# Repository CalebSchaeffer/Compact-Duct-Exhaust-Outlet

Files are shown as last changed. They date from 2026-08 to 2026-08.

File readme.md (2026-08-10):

# Compact Duct Exhaust Outlet
My final project for ENGR 1304 (Graphics). It was a 3d printable 4-inch exhaust outlet that took a circular input and transitioned it into a rectangular exhaust. Flaps were also in place to prevent stuff from getting in while the fan is off. 

This project was completed earlier in my CAD experience. My skills have improved since then, but expect some of the CAD to be a bit rough. 

# Assembly

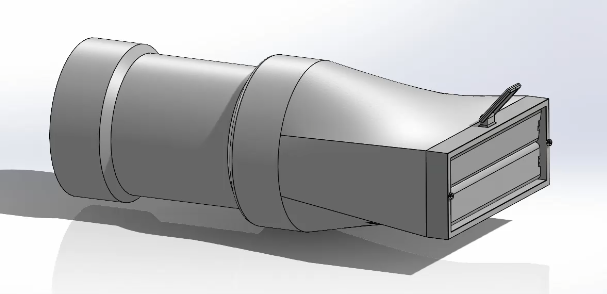
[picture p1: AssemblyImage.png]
AssemblyImage


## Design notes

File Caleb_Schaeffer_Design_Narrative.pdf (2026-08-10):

Schaeffer 1

Caleb Schaeffer
Mr. McLane
ENGR 1304
5 May 2026
Compact Duct Exhaust Outlet For this project, I designed an adapter that takes a 4-inch fan, and vents it out via a rectangular output with flaps to keep debris from going back through when air is not flowing. The assembly begins with the fan duct casing, just so that the end user can see what the adapter connects to, and that connects to the adapter. The adapter is made up of two primary parts. It has the transition piece, which takes the circular duct input and converts it to a rectangular output, and it has a piece that mounts to that which holds the flaps and mounting geometries. However, there are many more parts that went into this design/assembly.
The joints used are found at the hinges for the flaps, and on top of the flap casing, where a latch is found. To connect the flaps to the flap casing, they are press fit. To achieve this, the flap casing is made up of TPU (Thermoplastic Polyurethane), which has more flexible properties compared to other plastics, such as ABS (Acrylonitrile Butadiene Styrene), used for the other pieces. Because of the way that the joining mechanism works, the flaps are easily able to slide in given the flexibility of TPU, however, due to the shape of the joinery, they are unable to come out during typical use. Another example of this press-fit joinery is found on the top latch. The top latch connects at the top and serves as a way to mount the device to any fixtures necessary. Once again, because the casing is flexible, the latch is able to press fit on, and stay on during normal usage. Alternative ideas to this mounting were considered, such as mounting bearings and making the whole assembly two pieces that could be screwed together, however, the press-fit joinery was decided upon due to its simplicity and functionality. Every single hinge found on this design is a 1 DOF (Degree of Freedom) joint, which keeps things simple and secure.
There were many design considerations that were taken into account for this project to come to life. One of them was the understanding that additive manufacturing was to be used for the final manufacturing of the device. As such, the materials are made in additive manufacturing friendly materials, such as ABS and TPU. The only pieces that are metal are standardized screws, such as the M2 screws. As such, the entire assembly is based on the metric system due to my personal familiarity with it as well as the dominance of metric in the additive manufacturing space. The design had 3D printing as its preferred method of additive manufacturing at heart, and as such many more design considerations were taken for that. The majority of the design is able to be printed without supports, and the walls are all multiples of 0.4mm, with most of them being 4mm thick. This is important, as 0.4mm is the standardized nozzle size for most 3D printers, and most walls are able to be set to 4mm thick, meaning that you get clean surfaces and extrusion from a 3D printer. Another consideration that was made specifically in the spirit of 3D printing was the chamfers. Due to a 3D printing phenomenon called “elephant’s foot” parts may come out with the bottom surfaces that are attached to the bed looking bulged. Adding a chamfer of ~0.2mm helps with this, as if such a phenomenon happens, then it is quickly hidden away, and keeps the corner looking perfectly square. The design is also able to be modified as to the end user’s goals. If the end user is using a different duct fan, then they are able to edit the dimensions of the adapter to meet their parameters. Clearance was also important to the project due to the dimensional accuracy of the 3D printer used, however, in SolidWorks, these are not added in most sections. This is because most 3D printer users are familiar with their printers, know the shrinkage per material, and know the overall dimensional accuracy of their 3D printer. Due to this, the end user is able to go back into the SolidWorks file and edit the file to their specification. All of these considerations came together to make a design that works elegantly, is able to be manufactured easily, and can be easily scaled.
A few technical difficulties were found along the way for this design. One technical difficulty I faced was the usage of SolidWorks. Due to not being as familiar with SolidWorks as I am with other CAD programs, I found that there were particular functions or sketching tools that I needed that I was unable to find quickly. Eventually, I was able to find everything that was needed, however, this led to a significant time bump. Another technical difficulty was with poor planning as to the design of the project. At the start of the project, I did not have the dimensions for everything, and I was not certain what the end result would fully look like. To minimize any issues and further complicating things, I made the majority of the project in another CAD program that I am more familiar with to make sure everything worked up to spec, and then moved it over to SolidWorks. However, the majority of the designing was still done in SolidWorks, until I wasn’t certain how I wanted a certain piece to turn out as.

Standard M2 screws were not designed by me. They were created by Ioan Skurka and posted on GrabCAD.
Material Properties:

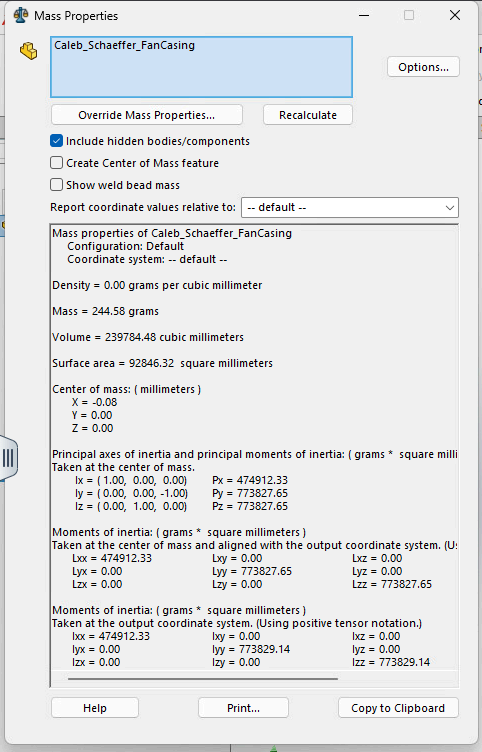
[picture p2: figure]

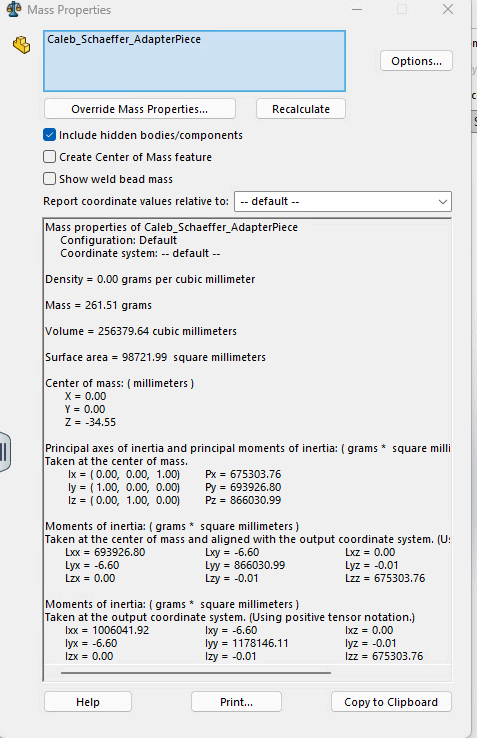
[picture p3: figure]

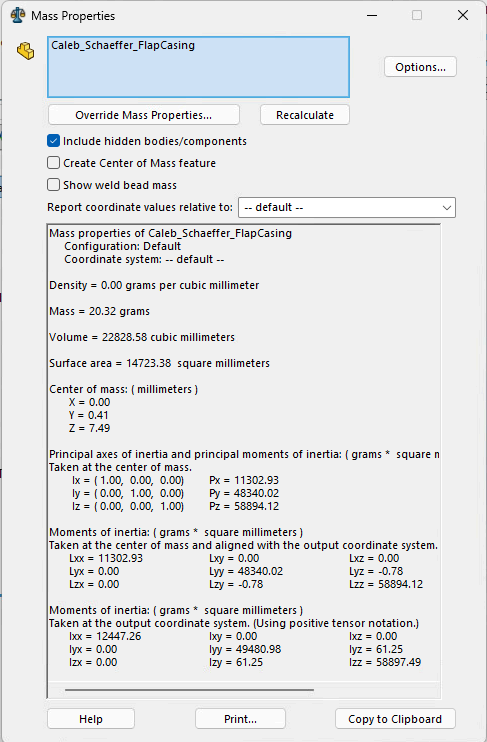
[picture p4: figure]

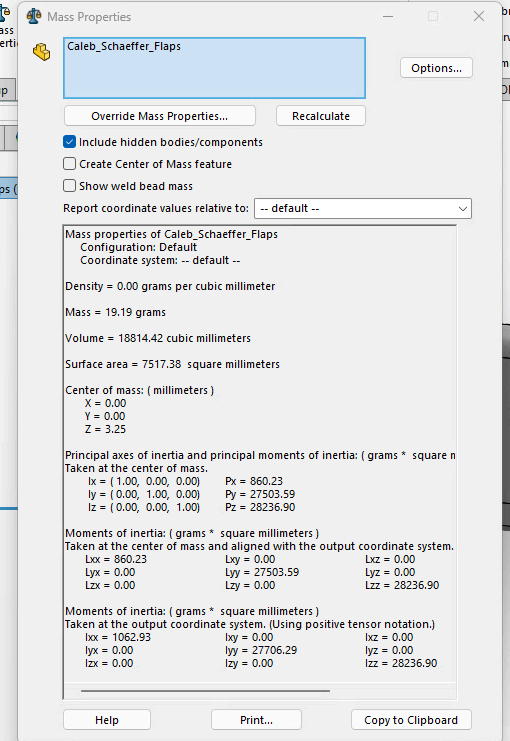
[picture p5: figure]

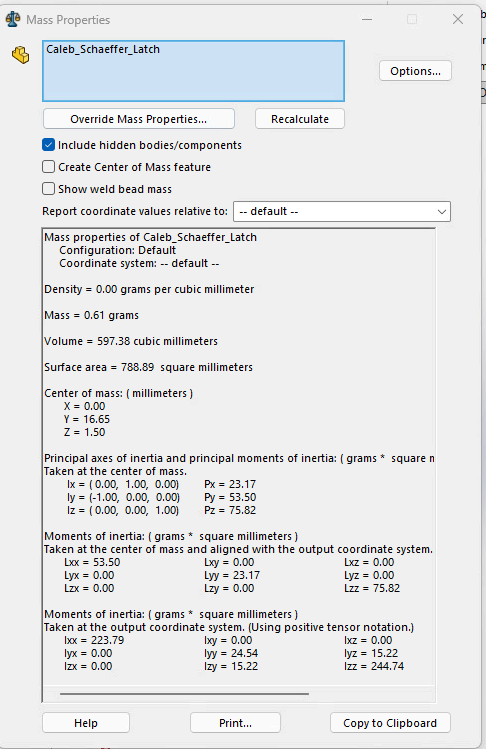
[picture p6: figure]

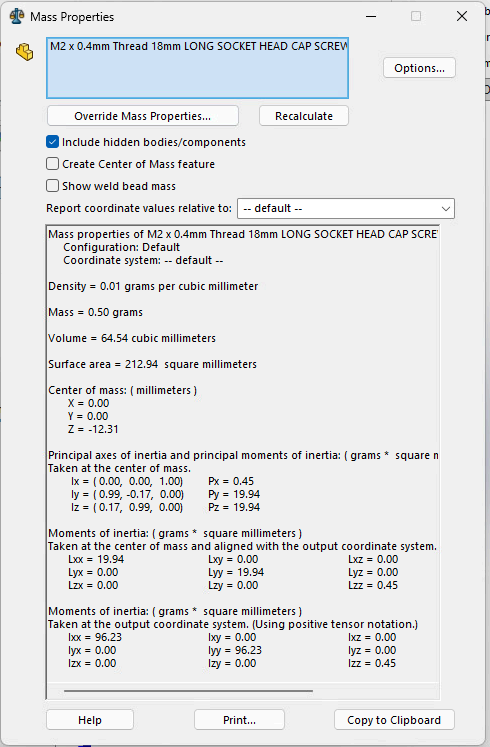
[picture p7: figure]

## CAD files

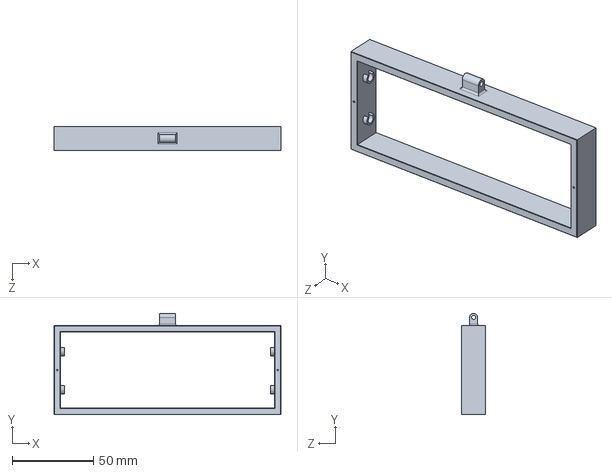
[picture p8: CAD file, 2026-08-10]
Caleb_Schaeffer_FlapCasing.SLDPRT
140.0 x 62.5 x 15.0 mm

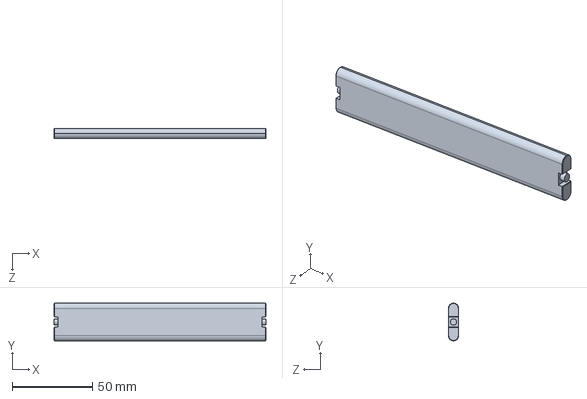
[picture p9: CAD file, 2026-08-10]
Caleb_Schaeffer_Flaps.SLDPRT
132.0 x 23.5 x 6.50 mm

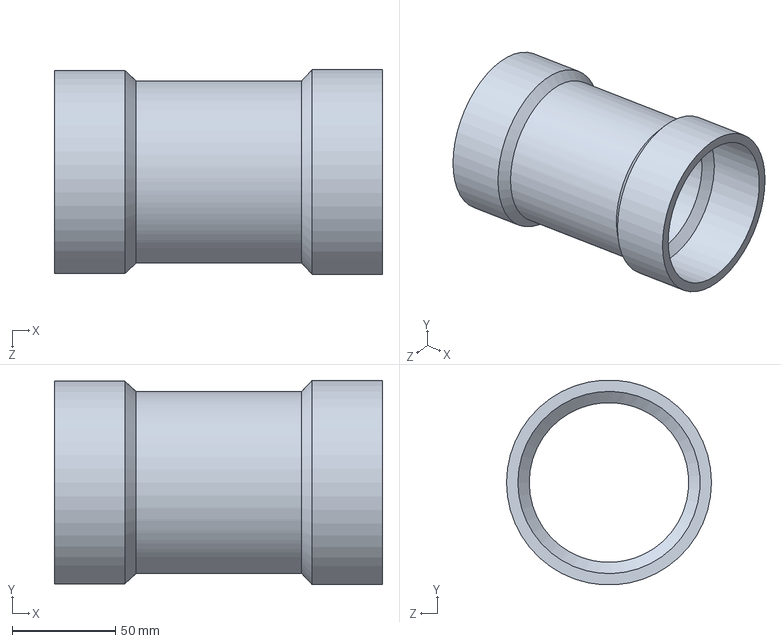
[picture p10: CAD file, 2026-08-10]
Caleb_Schaeffer_FanCasing.SLDPRT
158.6 x 98.9 x 99.1 mm

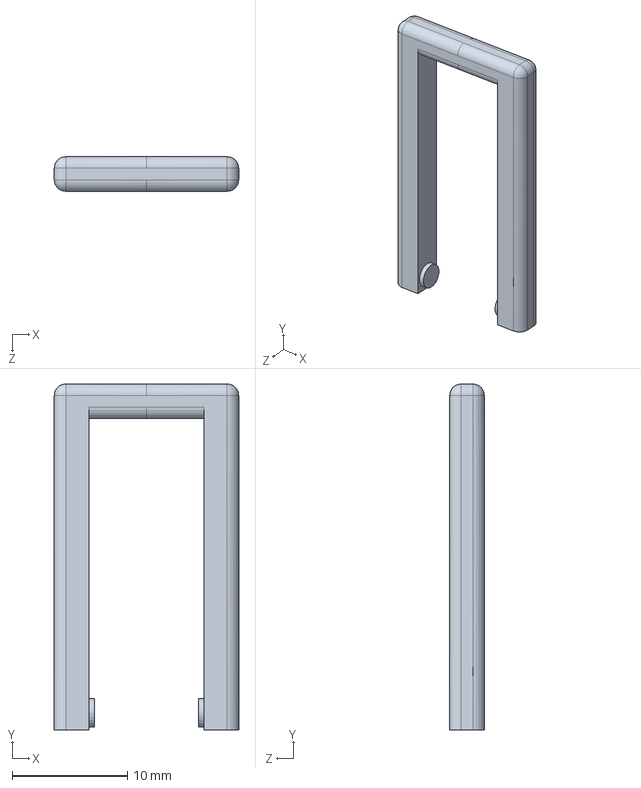
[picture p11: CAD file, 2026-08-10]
Caleb_Schaeffer_Latch.SLDPRT
16.0 x 30.0 x 3.00 mm

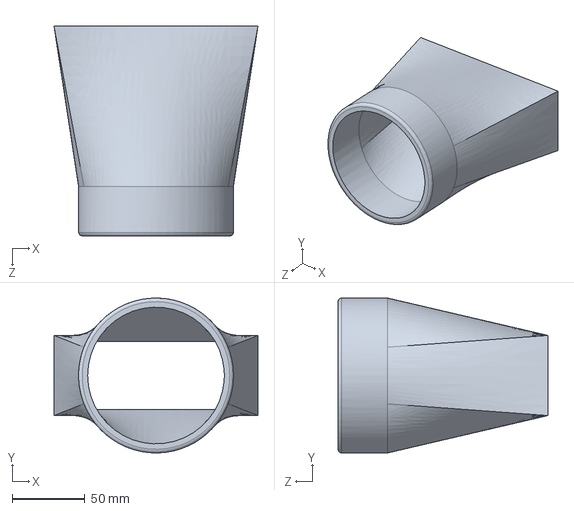
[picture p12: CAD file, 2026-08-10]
Caleb_Schaeffer_AdapterPiece.SLDPRT
140.0 x 106.3 x 144.0 mm

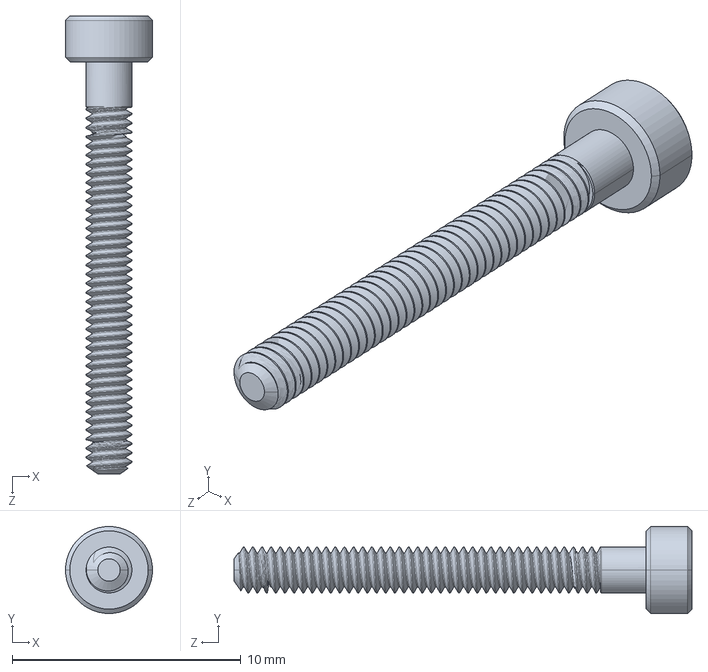
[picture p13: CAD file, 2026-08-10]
M2 x 0.4mm Thread 18mm LONG SOCKET HEAD CAP SCREW.STEP
3.80 x 3.80 x 20.0 mm

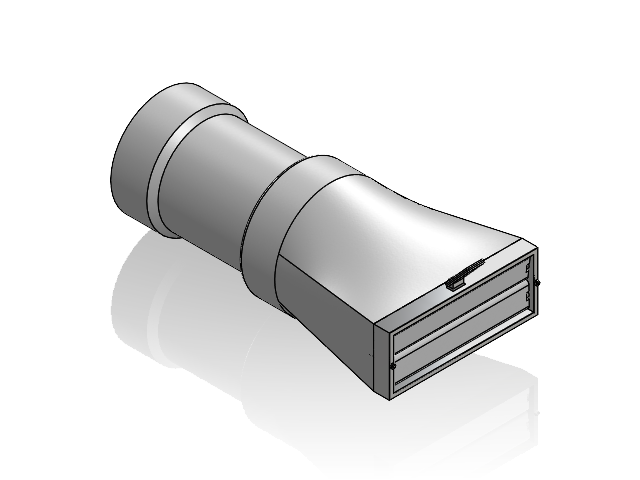
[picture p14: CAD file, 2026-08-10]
Caleb_Schaeffer_Assembly.SLDASM
FanCasing
LoftingPart
FlapCasing
Flaps x 2
TopConnection
M2 x 0.4mm Thread 18mm LONG SOCKET HEAD CAP SCREW.step x 2

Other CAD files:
Caleb_Schaeffer_Drawings.SLDDRW

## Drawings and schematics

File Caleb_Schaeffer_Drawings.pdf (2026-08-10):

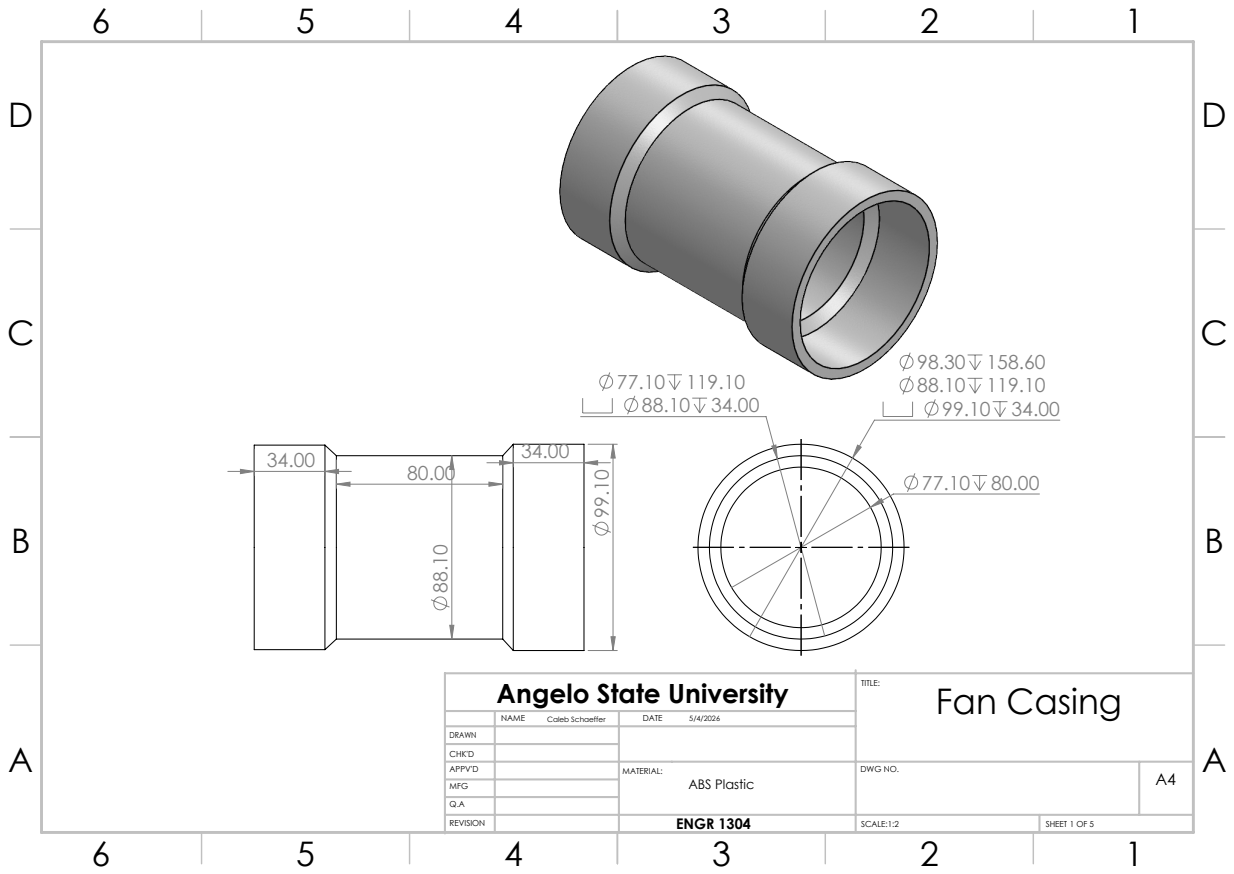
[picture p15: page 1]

Angelo State University Caleb Schaeffer 5/4/2026 | TITLE: Fan Casing

NAME | DATE

DRAWN
CHK'D
APPV'D | | MATERIAL: | DWG NO. | A4 ABS Plastic
MFG
Q.A
REVISION | | ENGR 1304 | SCALE:1:2 | SHEET 1 OF 5

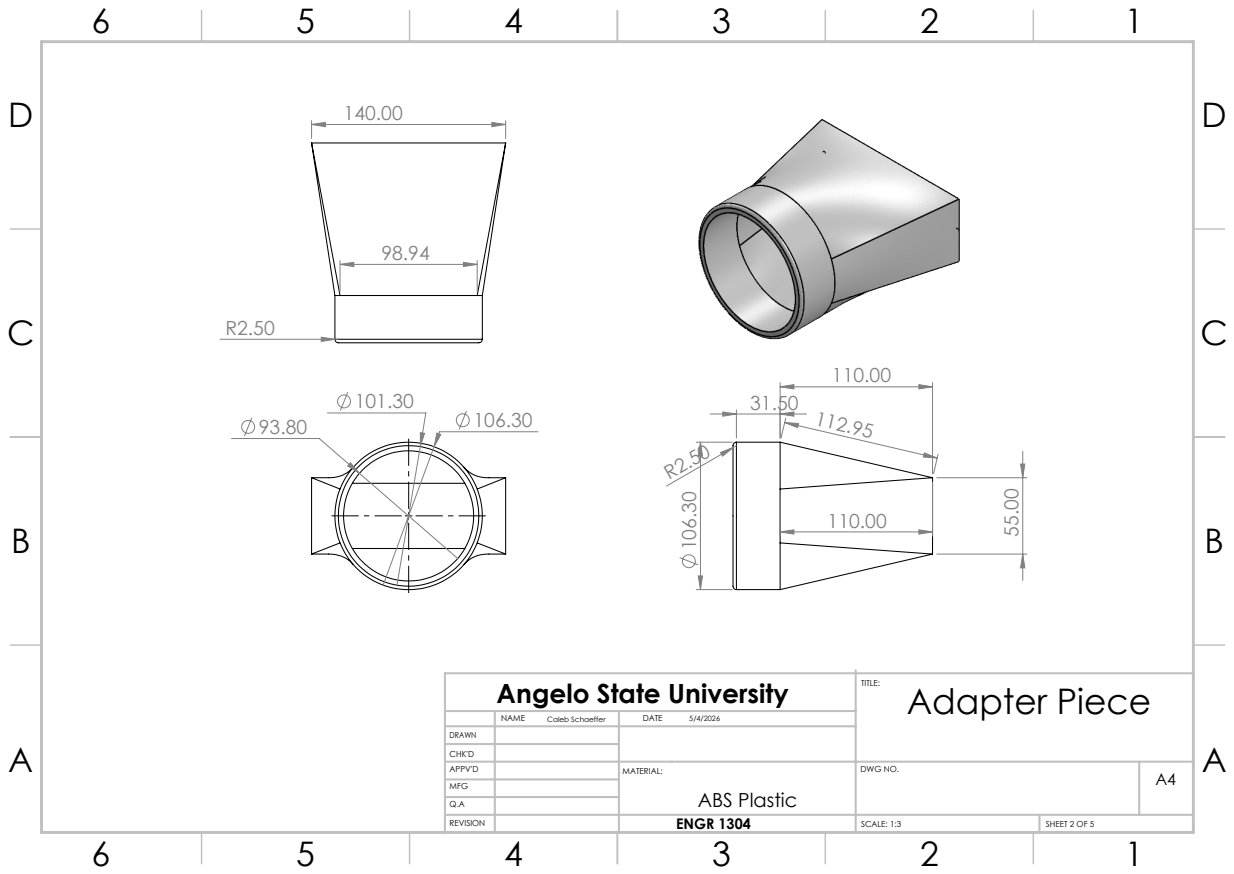
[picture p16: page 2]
SCALE: 1:3; SHEET 2 OF 5

Angelo State University Caleb Schaeffer 5/4/2026 | TITLE: Adapter Piece

NAME | DATE

DRAWN
CHK'D
APPV'D | | MATERIAL: ABS Plastic | DWG NO. | A4
MFG

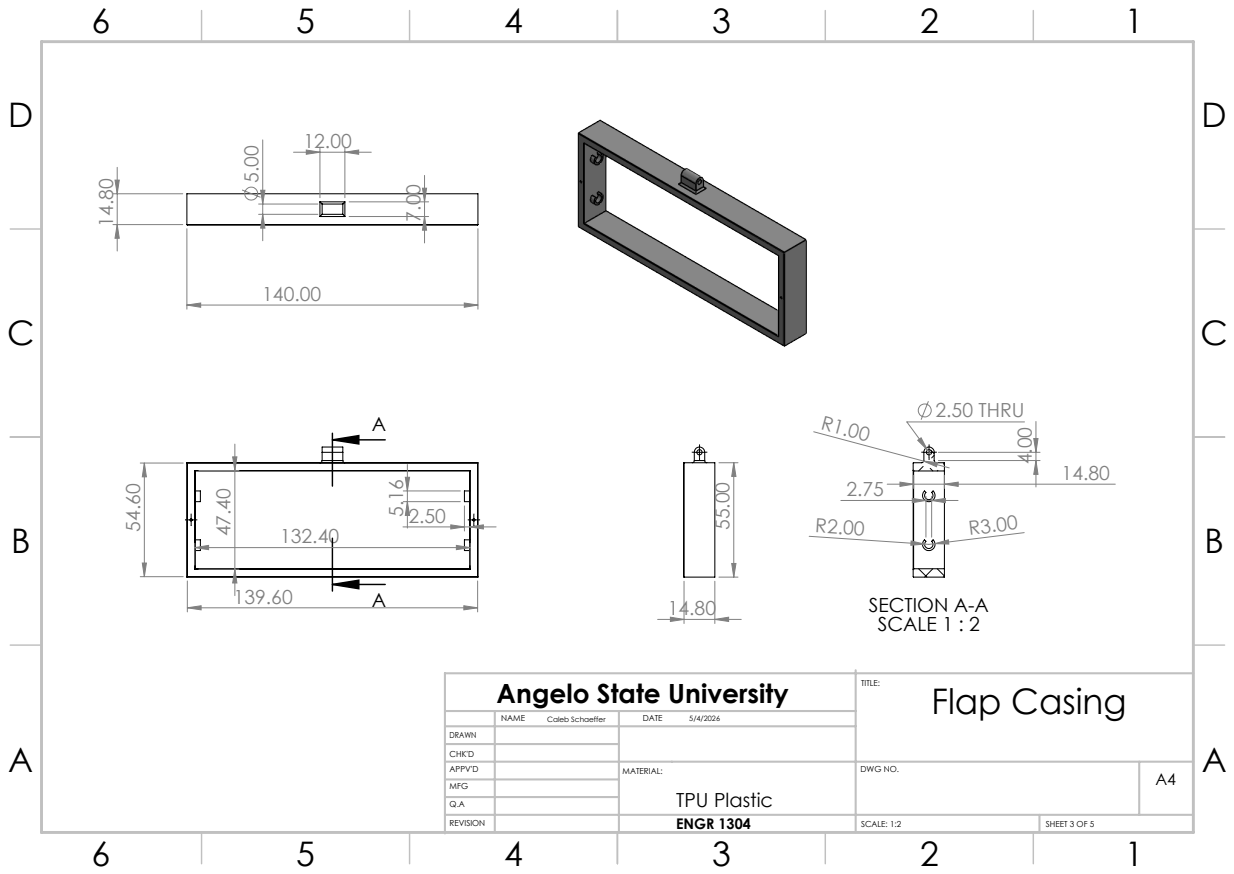
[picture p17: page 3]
2.50 THRU; SECTION A-A SCALE 1 : 2; SCALE: 1:2; SHEET 3 OF 5

Angelo State University Caleb Schaeffer 5/4/2026 | TITLE: Flap Casing

NAME | DATE

DRAWN
CHK'D
APPV'D | | MATERIAL: TPU Plastic | DWG NO. | A4
MFG

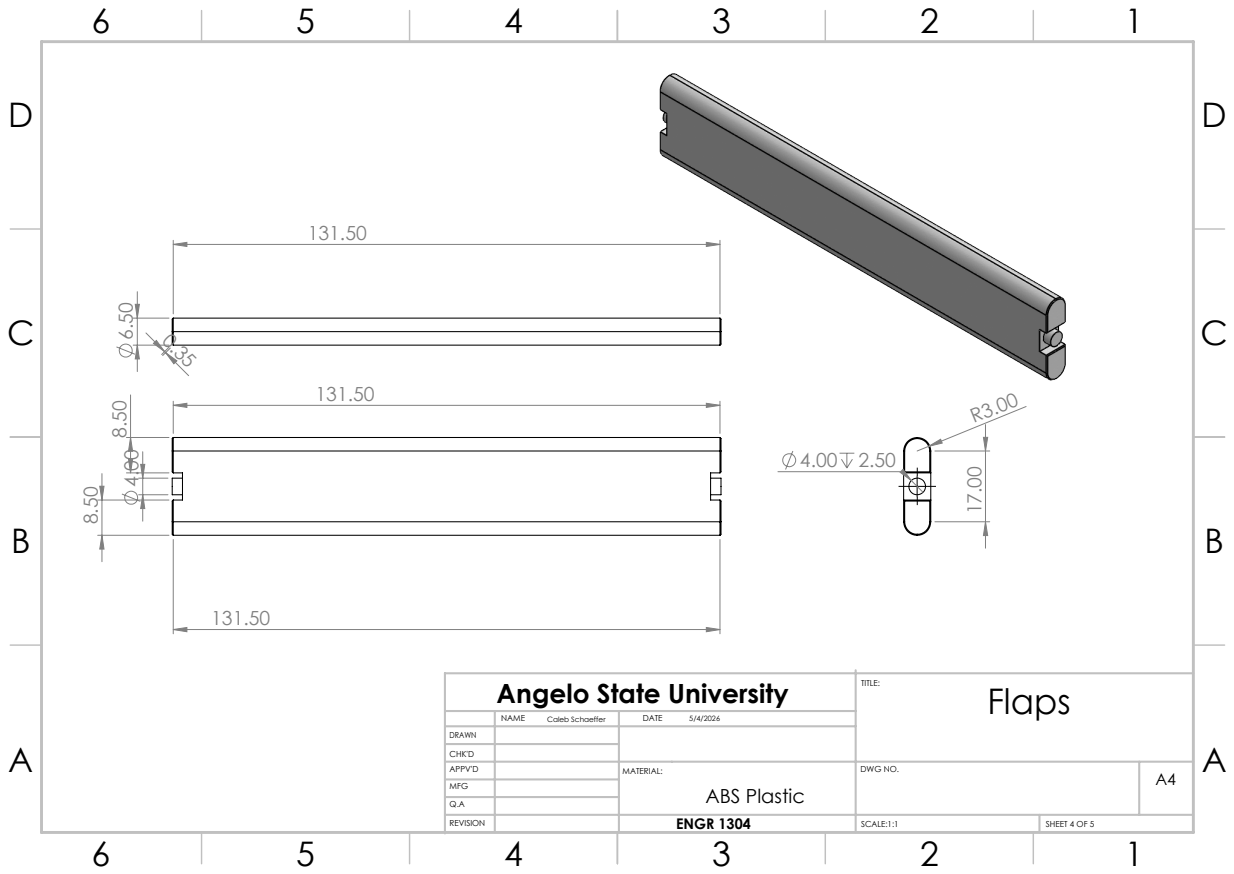
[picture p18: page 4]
SCALE:1:1; SHEET 4 OF 5

Angelo State University Caleb Schaeffer 5/4/2026 | TITLE: Flaps

NAME | DATE

DRAWN
CHK'D
APPV'D | | MATERIAL: ABS Plastic | DWG NO. | A4
MFG

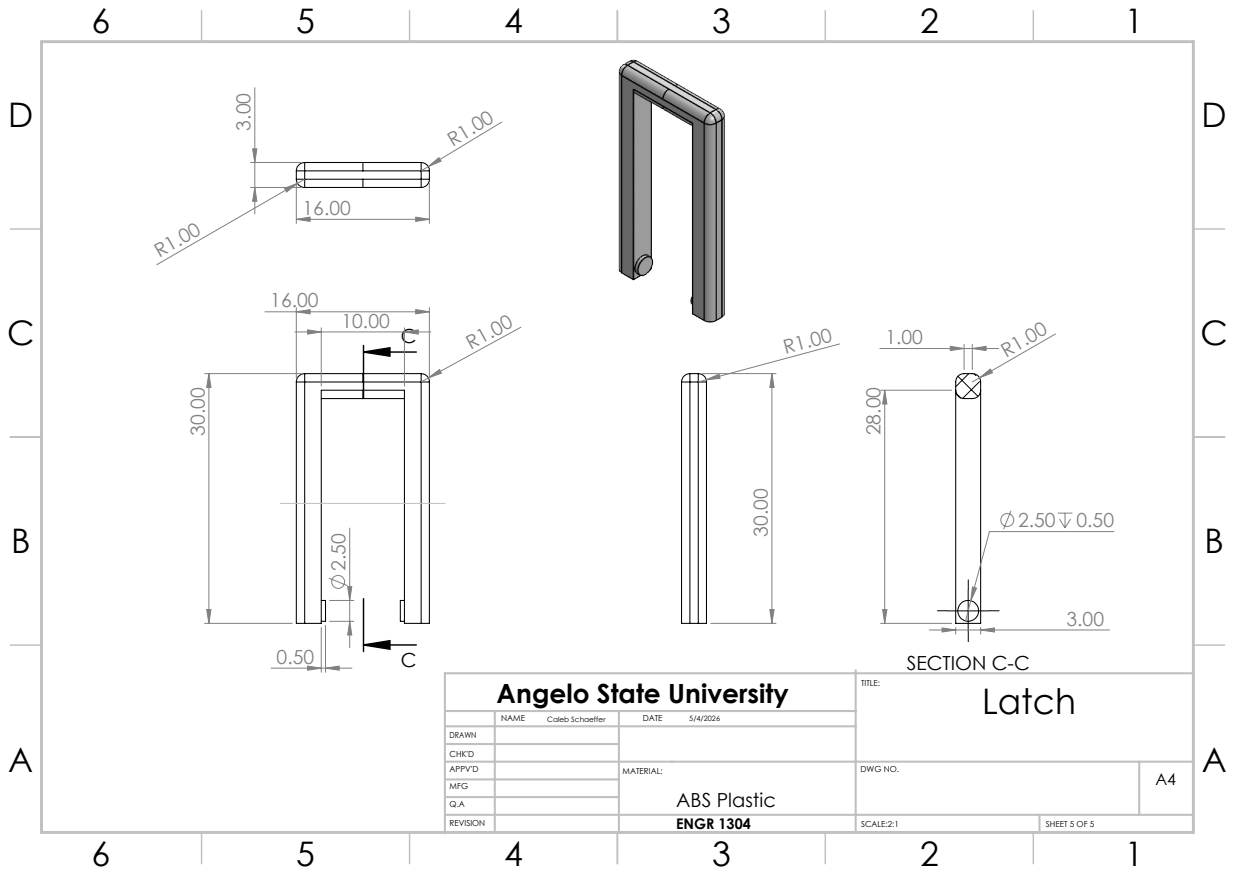
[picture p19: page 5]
SECTION C-C; SCALE:2:1; SHEET 5 OF 5

Angelo State University Caleb Schaeffer 5/4/2026 | TITLE: Latch

NAME | DATE

DRAWN
CHK'D
APPV'D | | MATERIAL: ABS Plastic | DWG NO. | A4
MFG
